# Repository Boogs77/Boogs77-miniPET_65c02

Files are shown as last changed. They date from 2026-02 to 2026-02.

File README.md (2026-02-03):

# miniPET: 65C02-Based Retro Computer

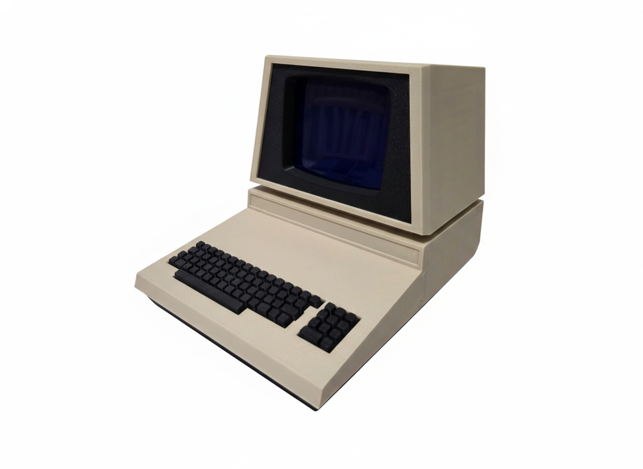
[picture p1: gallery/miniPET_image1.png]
Main Photo


The **Boogs77-miniPET** is a compact, high-performance 8-bit computer inspired by the iconic Commodore PET aesthetics. Built around the **W65C02S** processor, this project utilizes the modular architecture of the [BO6502 System](https://github.com/Boogs77/BO6502_65C02-based_modular_computer) and integrates it into a custom-designed, 3D-printed enclosure.

---

## 🧠 System Architecture & Modules

The internal logic of the miniPET is derived directly from the modular boards of the BO6502 project. Each core component follows the same electrical and logical specifications:

### ⚙️ Core Processing Unit (CPU, RAM, ROM)
The system's "brain" and memory management are based on the high-reliability design of the BO6502:
* **CPU:** Western Design Center **W65C02S**, allowing for modern high-speed operation while maintaining full 6502 compatibility. Reference: [BO6502 CPU](https://github.com/Boogs77/BO6502_65C02-based_modular_computer/tree/main/BO6502%20CPU).
* **Clock:** System operates with a stable **1MHz** clock frequency. Reference: [BO6502 CPU](https://github.com/Boogs77/BO6502_65C02-based_modular_computer/tree/main/BO6502%20CPU).

### 🗺️ Memory Map
The memory layout is organized to ensure compatibility with the system firmware and modular hardware:
* **RAM (32KB):** Mapped from **$0000** to **$7FFF**. Reference: [BO6502 RAM](https://github.com/Boogs77/BO6502_65C02-based_modular_computer/tree/main/BO6502%20RAM).
* **ROM (32KB):** Mapped from **$8000** to **$FFFF**. Reference: [BO6502 ROM](https://github.com/Boogs77/BO6502_65C02-based_modular_computer/tree/main/BO6502%20ROM).

### 📟 Display Interface (BIGLCD)
The visual output is handled by the **BIGLCD** module. 
* **Addressing:** The module is mapped and accessible at memory address **$D19X**.
* **Reference:** [BO6502 BIGLCD](https://github.com/Boogs77/BO6502_65C02-based_modular_computer/tree/main/BO6502%20BIGLCD).

### ⌨️ Keyboard Input
Input is managed via a dedicated matrix keyboard interface.
* **Addressing:** The keyboard is mapped and accessible at memory address **$D18X**.
* **Reference:** [BO6502 KeyBoard Module](https://github.com/Boogs77/BO6502_65C02-based_modular_computer/tree/main/BO6502%20KEYb).

### 🔌 Serial Communication
Asynchronous communication is provided for external terminal access.
* **Addressing:** Accessible at the **$CXXX** memory range.
* **Reference:** [BO6502 Serial Module](https://github.com/Boogs77/BO6502_65C02-based_modular_computer/tree/main/BO6502%20SERIAL).

---

## 💻 Software & Firmware

The Boogs77-miniPET features a classic software environment for 6502 enthusiasts:
* **System Monitor:** The computer implements the legendary **Wozmon** monitor, providing a low-level interface for memory inspection and machine code execution.
* **Microsoft BASIC:** The firmware includes **MS BASIC**, allowing for high-level programming.
* **Execution:** BASIC can be launched directly from the monitor by executing from location **$8000**.

---

## 🏗️ Enclosure & 3D Design

One of the most distinctive features of this project is its custom case, modified using **Autodesk Fusion 360** from the original design at [commodorepetmini.com](https://commodorepetmini.com/). The case was printed on an **Anycubic Kobra S1**.

<p align="center">
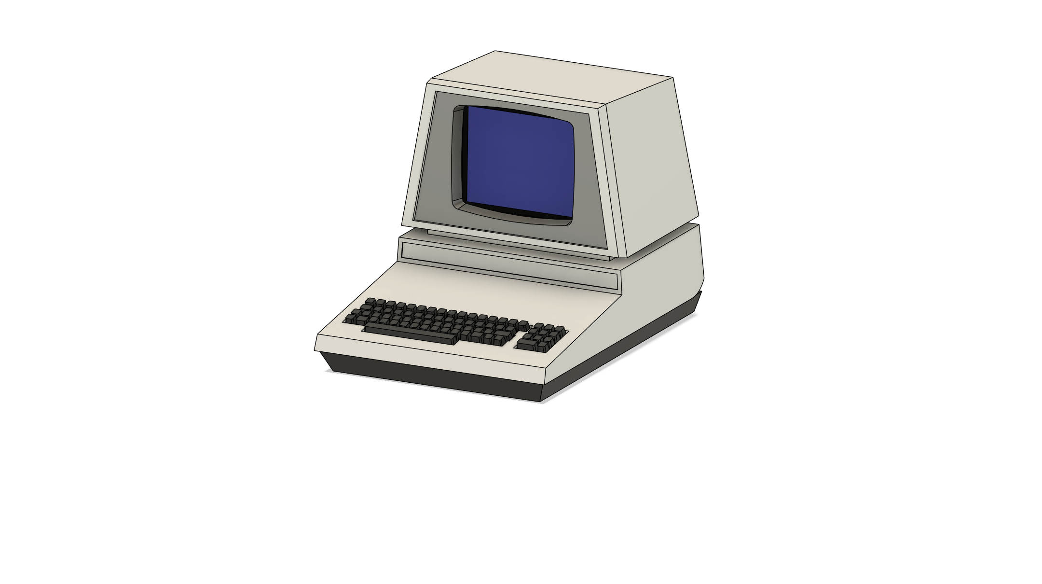
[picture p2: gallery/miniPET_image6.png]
  
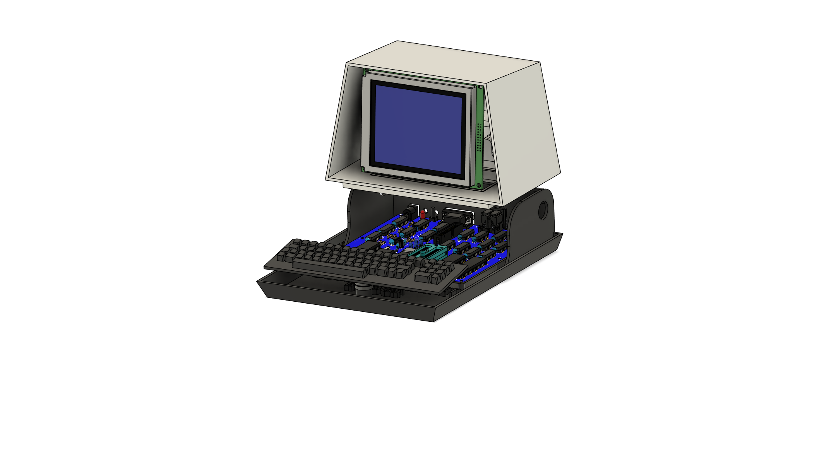
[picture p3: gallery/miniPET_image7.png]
  
</p>

---

## 📋 Bill of Materials (BOM)

| Component | Description | Quantity |
| :--- | :--- | :--- |
| **W65C02S** | CMOS 8-bit Microprocessor | 1 |
| **AS6C62256** | 32K x 8 Static RAM | 1 |
| **AT28C256** | 32K x 8 EEPROM | 1 |
| **W65C22 (VIA)** | Versatile Interface Adapter | 2 |
| **NE555** | Precision Timer (Reset Circuit) | 1 |
| **BIGLCD** | High Contrast LCD Module | 1 |

👉 **[View Full BOM for Components](https://github.com/Boogs77/Boogs77-miniPET_65c02/blob/main/export/miniPET_bom.md)**

---

## 🔗 Useful Links & Resources

To replicate this build, you can refer to the following hardware files:

* **Eagle Design Files:** [Project PCB Schematics & Layouts](https://github.com/Boogs77/Boogs77-miniPET_65c02/tree/main/eagle)
* **CPU Module:** [BO6502 CPU Reference](https://github.com/Boogs77/BO6502_65C02-based_modular_computer/tree/main/BO6502%20CPU)
* **ROM Module:** [BO6502 ROM Reference](https://github.com/Boogs77/BO6502_65C02-based_modular_computer/tree/main/BO6502%20ROM)
* **RAM Module:** [BO6502 RAM Reference](https://github.com/Boogs77/BO6502_65C02-based_modular_computer/tree/main/BO6502%20RAM)
* **Serial Module:** [BO6502 Serial Reference](https://github.com/Boogs77/BO6502_65C02-based_modular_computer/tree/main/BO6502%20SERIAL)
* **Keyboard Module:** [BO6502 KeyBoard Reference](https://github.com/Boogs77/BO6502_65C02-based_modular_computer/tree/main/BO6502%20KEYb)
* **Display Module:** [BO6502 BIGLCD Reference](https://github.com/Boogs77/BO6502_65C02-based_modular_computer/tree/main/BO6502%20BIGLCD)

---

## 🖼️ Project Gallery

Internal assembly and detailed realization stages:

<p align="center">
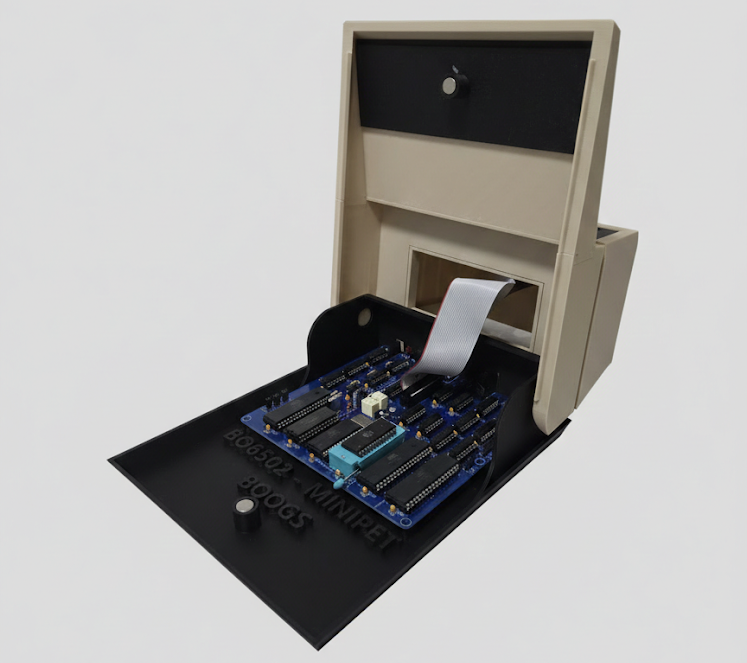
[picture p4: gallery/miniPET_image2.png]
  
  
</p>
<p align="center">
  
  
</p>

---
*Created by Boogs77 - 2026*

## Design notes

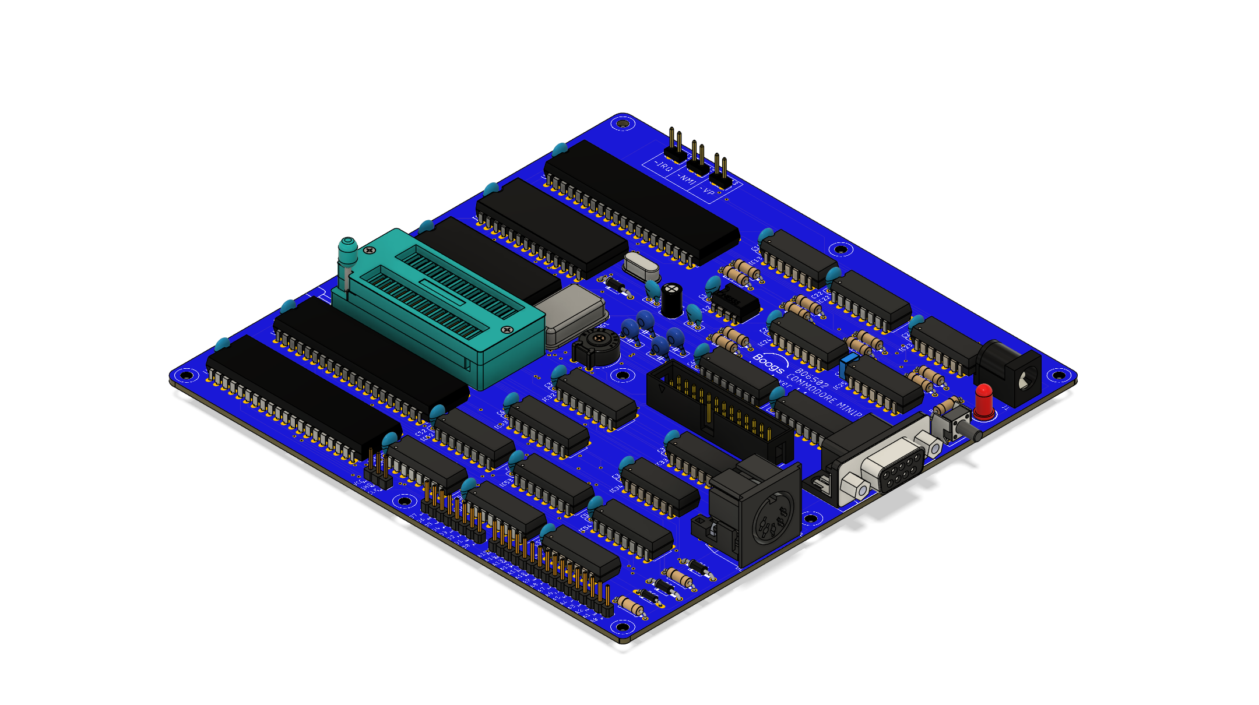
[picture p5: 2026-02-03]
gallery/miniPET_final.png

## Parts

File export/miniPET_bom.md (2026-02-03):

# 📑 Bill of Materials (BOM): miniPET 1.0

**Project:** miniPET
**Export Date:** 02/02/2026
**Source File:** `miniPET_final.sch`

---

### 🧠 Integrated Circuits (IC) & Logic
| Qty | Part | Value | Description | Package |
| :--- | :--- | :--- | :--- | :--- |
| 1 | **U11** | 65C02 | 8-bit CMOS CPU | DIL40 |
| 2 | **U51, U61** | 65C22 | VIA (Versatile Interface Adapter) | DIL40 |
| 1 | **U43** | 65C51 | ACIA (Serial Interface) | DIL28 |
| 1 | **IC21** | HM62256 | Static RAM (SRAM) | DIL28-6 |
| 1 | **ZX1-28C256** | 228-1277-00-0602J | Zero Insertion Force (ZIF) Socket | 228-1277-00-0602J |
| 7 | **IC22, IC32, IC42, IC54, IC55, IC56, IC63** | 74AC138N | 3-to-8 Decoder/Demultiplexer | DIL16 |
| 4 | **IC23, IC24, IC33, IC34** | 74HC08N | Quad 2-input AND gate | DIL14 |
| 2 | **IC52, IC53** | 74HCT595N | 8-bit Shift Register with output latch | DIL16 |
| 1 | **IC41** | MAX232 | RS232 Transceiver | DIL16 |
| 1 | **IC12** | NE555 | General purpose bipolar Timer | DIL-08 |
| 1 | **IC13** | 74HCT04N | Hex INVERTER | DIL14 |
| 1 | **IC57** | 74HCT14N | Hex Schmitt Trigger Inverter | DIL14 |
| 1 | **IC25** | 74HCT00N | Quad 2-input NAND gate | DIL14 |

---

### ⚡ Resistors & Potentiometers
| Qty | Part | Value | Description | Package |
| :--- | :--- | :--- | :--- | :--- |
| 5 | **R14, R15, R16, R17, R18** | 3.3K | Standard Resistor | 0207/10 |
| 2 | **R1, R31** | 330 | Standard Resistor | 0207/10 |
| 2 | **R11, R41** | 1M | Standard Resistor | 0207/10 |
| 1 | **R12** | 47k | Standard Resistor | 0207/10 |
| 1 | **R13** | 1k | Standard Resistor | 0207/10 |
| 1 | **R51** | 15K | Standard Resistor | 0207/10 |
| 1 | **R62** | 220 | Standard Resistor | 0207/10 |
| 1 | **R61** | 10K | Potentiometer | PT-10 |

---

### 🔋 Capacitors
| Qty | Part | Value | Description | Package |
| :--- | :--- | :--- | :--- | :--- |
| 22 | **C11, C13-15, C21-25, C31-34, C46-48, C51-57, C61, C63** | 100n | Ceramic Capacitor (Decoupling) | C025-025X050 |
| 4 | **C41, C42, C43, C44** | 1u | Ceramic Capacitor | C050-025X075 |
| 1 | **C12** | 10uF | Polarized Capacitor | B45181A |
| 1 | **C45** | 20p | Ceramic Capacitor (for Crystal) | C025-025X050 |

---

### 💎 Diodes & Crystals
| Qty | Part | Value | Description | Package |
| :--- | :--- | :--- | :--- | :--- |
| 1 | **Q41** | 1.8432MHz | Crystal | HC49/S |
| 1 | **QG1** | - | Crystal Oscillator | DIL14S |
| 3 | **D41, D51, D61** | BS140 / SB140 | Diode (Equiv. 1N4004) | DO41-10 |
| 1 | **D52** | 1N4148 | Fast Signal Diode | DO35-7 |
| 1 | **LED1** | RED | 5mm LED | LED5MM |

---

### 🔌 Connectors, Switches & Display
| Qty | Part | Value | Description | Package |
| :--- | :--- | :--- | :--- | :--- |
| 1 | **LCD1** | DS-G160128STBWW | Graphic LCD | PAK100 |
| 1 | **J1** | POWER | DC Power Jack | SPC4078 |
| 1 | **X1** | RS232-DB9 | SUB-D 9-pin Connector | F09HP |
| 1 | **X2** | DIN 5 pin | Female DIN Connector | MAB5SH |
| 1 | **SW1** | MOMENTARY | Momentary Pushbutton (Reset) | TACTILE_RA |
| 11 | **JP1, JP11-13, JP2A-B, JP3A-D** | - | Jumper Headers | JP1 / JP2 / JP4 |

---

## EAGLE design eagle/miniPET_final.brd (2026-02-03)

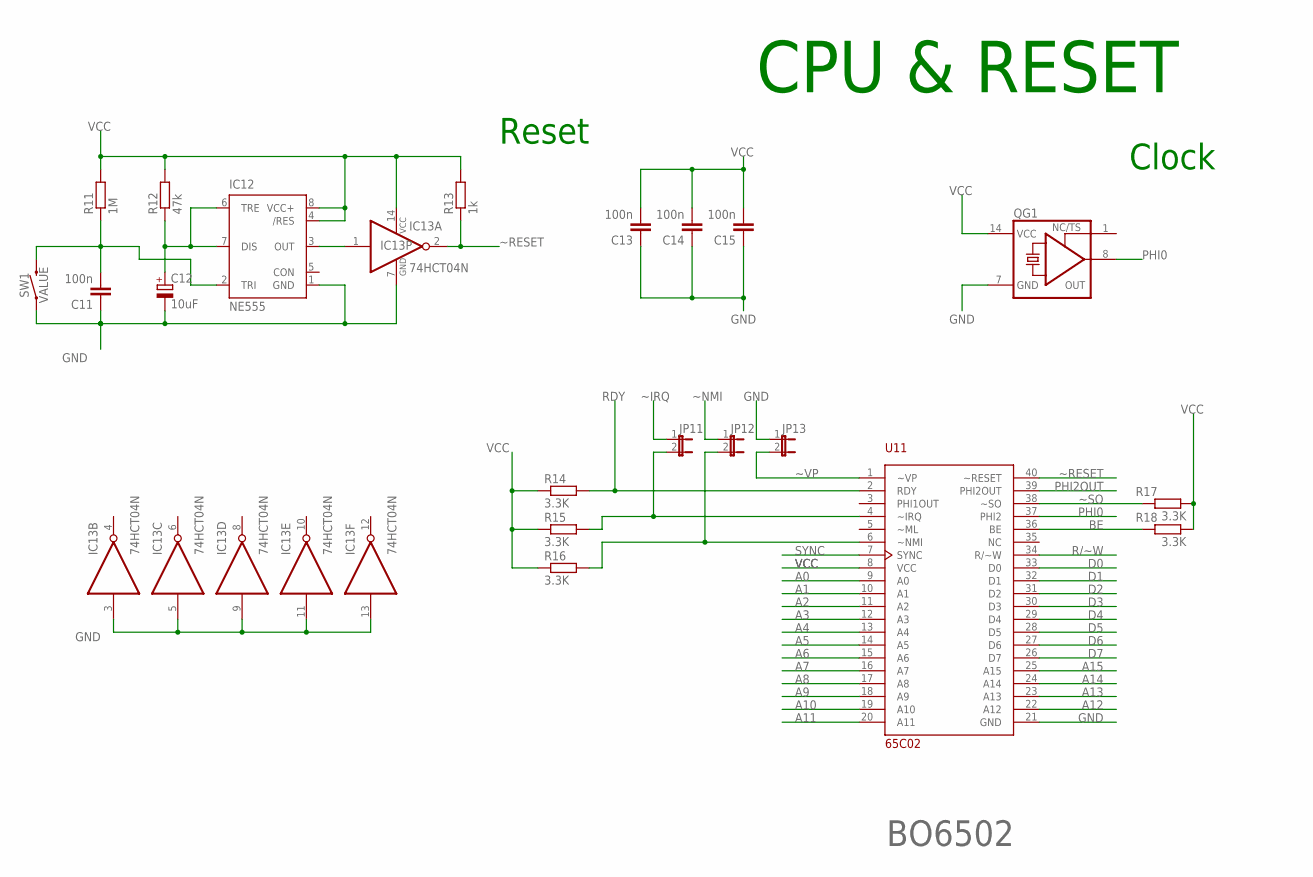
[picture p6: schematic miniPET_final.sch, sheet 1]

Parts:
C11, C13, C14, C15: 100n; C025-025X050
C12: 10uF; B45181A
IC12: NE555; DIL-08
IC13: 74HCT04N; DIL14
JP11, JP12, JP13: JP1E; JP1
QG1: XO-14; DIL14S
R11: 1M; 0207/10
R12: 47k; 0207/10
R13: 1k; 0207/10
R14, R15, R16, R17, R18: 3.3K; 0207/10
SW1: MOMENTARY-SWITCH-SPST-PTH-RIGHT-ANGLE-8-020; TACTILE_SWITCH_PTH_RA_8-020
U11: 65C02; DIL40

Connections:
A0: U11.9 (A0); also elsewhere on the board
A1: U11.10 (A1); also elsewhere on the board
A2: U11.11 (A2); also elsewhere on the board
A3: U11.12 (A3); also elsewhere on the board
A4: U11.13 (A4); also elsewhere on the board
A5: U11.14 (A5); also elsewhere on the board
A6: U11.15 (A6); also elsewhere on the board
A7: U11.16 (A7); also elsewhere on the board
A8: U11.17 (A8); also elsewhere on the board
A9: U11.18 (A9); also elsewhere on the board
A10: U11.19 (A10); also elsewhere on the board
A11: U11.20 (A11); also elsewhere on the board
A12: U11.22 (A12); also elsewhere on the board
A13: U11.23 (A13); also elsewhere on the board
A14: U11.24 (A14); also elsewhere on the board
A15: U11.25 (A15); also elsewhere on the board
BE: R18.1, U11.36 (BE)
D0: U11.33 (D0); also elsewhere on the board
D1: U11.32 (D1); also elsewhere on the board
D2: U11.31 (D2); also elsewhere on the board
D3: U11.30 (D3); also elsewhere on the board
D4: U11.29 (D4); also elsewhere on the board
D5: U11.28 (D5); also elsewhere on the board
D6: U11.27 (D6); also elsewhere on the board
D7: U11.26 (D7); also elsewhere on the board
GND: C11.1, C12.-, C13.1, C14.1, C15.1, IC12.1 (GND), IC13.3 (I), IC13.5 (I), IC13.7 (GND), IC13.9 (I), IC13.11 (I), IC13.13 (I), JP13.1, QG1.7 (GND), SW1.1, U11.21 (GND); also elsewhere on the board
unnamed: JP11.2, R15.2, U11.4 (~IRQ)
unnamed: JP12.2, R16.2, U11.6 (~NMI)
unnamed: C12.+, IC12.6 (TRE), IC12.7 (DIS), R12.1
unnamed: C11.2, IC12.2 (TRI), R11.1, SW1.2
unnamed: IC12.3 (OUT), IC13.1 (I)
PHI0: QG1.8 (OUT), U11.37 (PHI2); also elsewhere on the board
PHI2OUT: U11.39 (PHI2OUT)
R/~W: U11.34 (R/~W); also elsewhere on the board
RDY: R14.2, U11.2 (RDY)
SYNC: U11.7 (SYNC)
VCC: C13.2, C14.2, C15.2, IC12.4 (/RES), IC12.8 (VCC+), IC13.14 (VCC), QG1.14 (VCC), R11.2, R12.2, R13.2, R14.1, R15.1, R16.1, R17.2, R18.2, U11.8 (VCC); also elsewhere on the board
~IRQ: JP11.1; also elsewhere on the board
~NMI: JP12.1
~RESET: IC13.2 (O), R13.1, U11.40 (~RESET); also elsewhere on the board
~SO: R17.1, U11.38 (~SO)
~VP: JP13.2, U11.1 (~VP)

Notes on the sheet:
BO6502
CPU & RESET
Clock
Reset

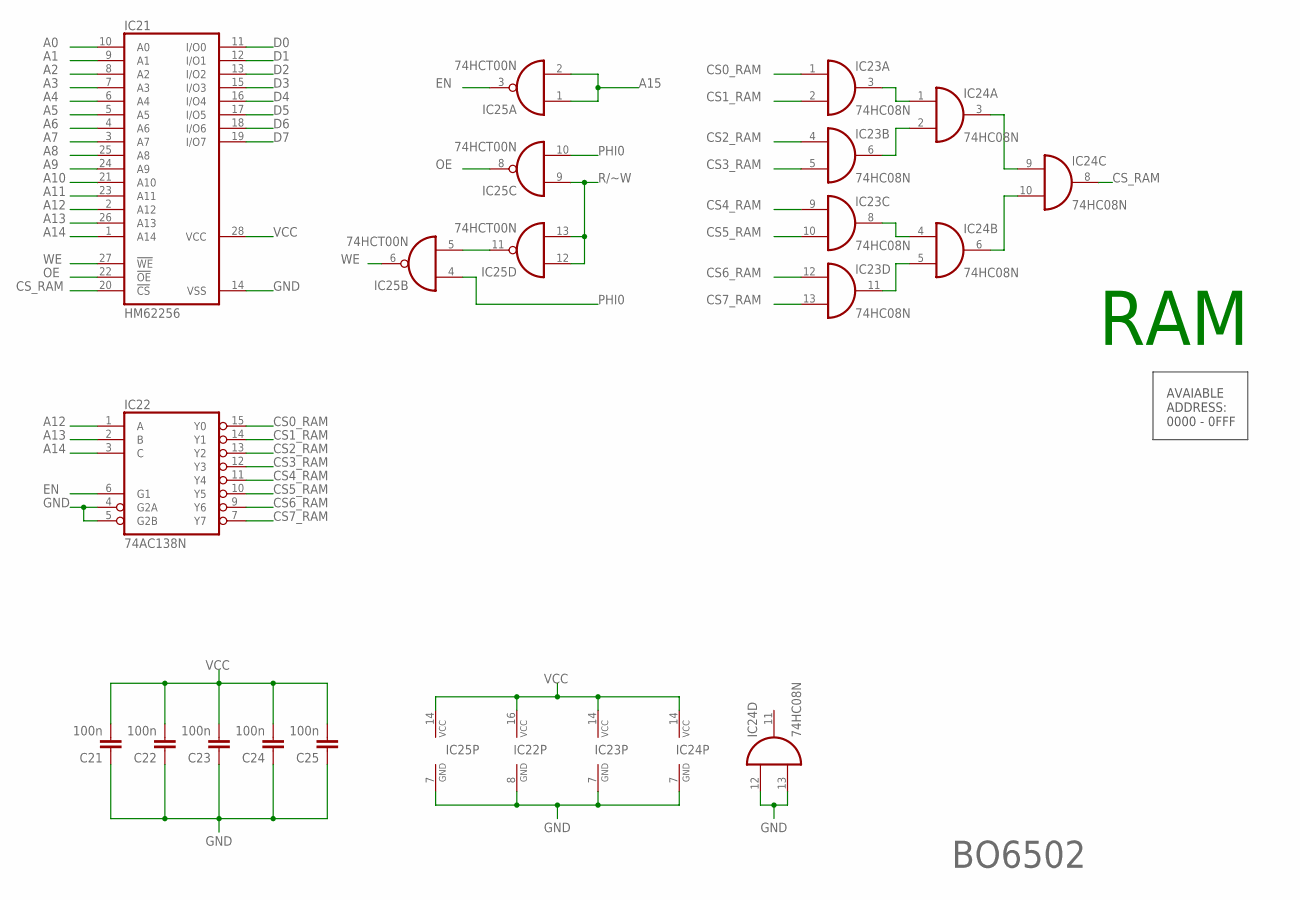
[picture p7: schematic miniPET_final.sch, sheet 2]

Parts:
C21, C22, C23, C24, C25: 100n; C025-025X050
IC21: HM62256; DIL28-6
IC22: 74AC138N; DIL16
IC23, IC24: 74HC08N; DIL14
IC25: 74HCT00N; DIL14

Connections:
A0: IC21.10 (A0); also elsewhere on the board
A1: IC21.9 (A1); also elsewhere on the board
A2: IC21.8 (A2); also elsewhere on the board
A3: IC21.7 (A3); also elsewhere on the board
A4: IC21.6 (A4); also elsewhere on the board
A5: IC21.5 (A5); also elsewhere on the board
A6: IC21.4 (A6); also elsewhere on the board
A7: IC21.3 (A7); also elsewhere on the board
A8: IC21.25 (A8); also elsewhere on the board
A9: IC21.24 (A9); also elsewhere on the board
A10: IC21.21 (A10); also elsewhere on the board
A11: IC21.23 (A11); also elsewhere on the board
A12: IC21.2 (A12), IC22.1 (A); also elsewhere on the board
A13: IC21.26 (A13), IC22.2 (B); also elsewhere on the board
A14: IC21.1 (A14), IC22.3 (C); also elsewhere on the board
A15: IC25.1 (I0), IC25.2 (I1); also elsewhere on the board
CS0_RAM: IC22.15 (Y0), IC23.1 (I0)
CS1_RAM: IC22.14 (Y1), IC23.2 (I1)
CS2_RAM: IC22.13 (Y2), IC23.4 (I0)
CS3_RAM: IC22.12 (Y3), IC23.5 (I1)
CS4_RAM: IC22.11 (Y4), IC23.9 (I0)
CS5_RAM: IC22.10 (Y5), IC23.10 (I1)
CS6_RAM: IC22.9 (Y6), IC23.12 (I0)
CS7_RAM: IC22.7 (Y7), IC23.13 (I1)
CS_RAM: IC21.20 (!CS), IC24.8 (O)
D0: IC21.11 (I/O0); also elsewhere on the board
D1: IC21.12 (I/O1); also elsewhere on the board
D2: IC21.13 (I/O2); also elsewhere on the board
D3: IC21.15 (I/O3); also elsewhere on the board
D4: IC21.16 (I/O4); also elsewhere on the board
D5: IC21.17 (I/O5); also elsewhere on the board
D6: IC21.18 (I/O6); also elsewhere on the board
D7: IC21.19 (I/O7); also elsewhere on the board
EN: IC22.6 (G1), IC25.3 (O)
GND: C21.1, C22.1, C23.1, C24.1, C25.1, IC21.14 (VSS), IC22.4 (G2A), IC22.5 (G2B), IC22.8 (GND), IC23.7 (GND), IC24.7 (GND), IC24.12 (I0), IC24.13 (I1), IC25.7 (GND); also elsewhere on the board
unnamed: IC25.5 (I1), IC25.11 (O)
unnamed: IC23.3 (O), IC24.1 (I0)
unnamed: IC23.6 (O), IC24.2 (I1)
unnamed: IC23.8 (O), IC24.4 (I0)
unnamed: IC23.11 (O), IC24.5 (I1)
unnamed: IC24.3 (O), IC24.9 (I0)
unnamed: IC24.6 (O), IC24.10 (I1)
OE: IC21.22 (!OE), IC25.8 (O)
PHI0: IC25.4 (I0), IC25.10 (I1); also elsewhere on the board
R/~W: IC25.9 (I0), IC25.12 (I0), IC25.13 (I1); also elsewhere on the board
VCC: C21.2, C22.2, C23.2, C24.2, C25.2, IC21.28 (VCC), IC22.16 (VCC), IC23.14 (VCC), IC24.14 (VCC), IC25.14 (VCC); also elsewhere on the board
WE: IC21.27 (!WE), IC25.6 (O)

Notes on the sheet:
RAM
BO6502
AVAIABLE ADDRESS: 0000 - 0FFF

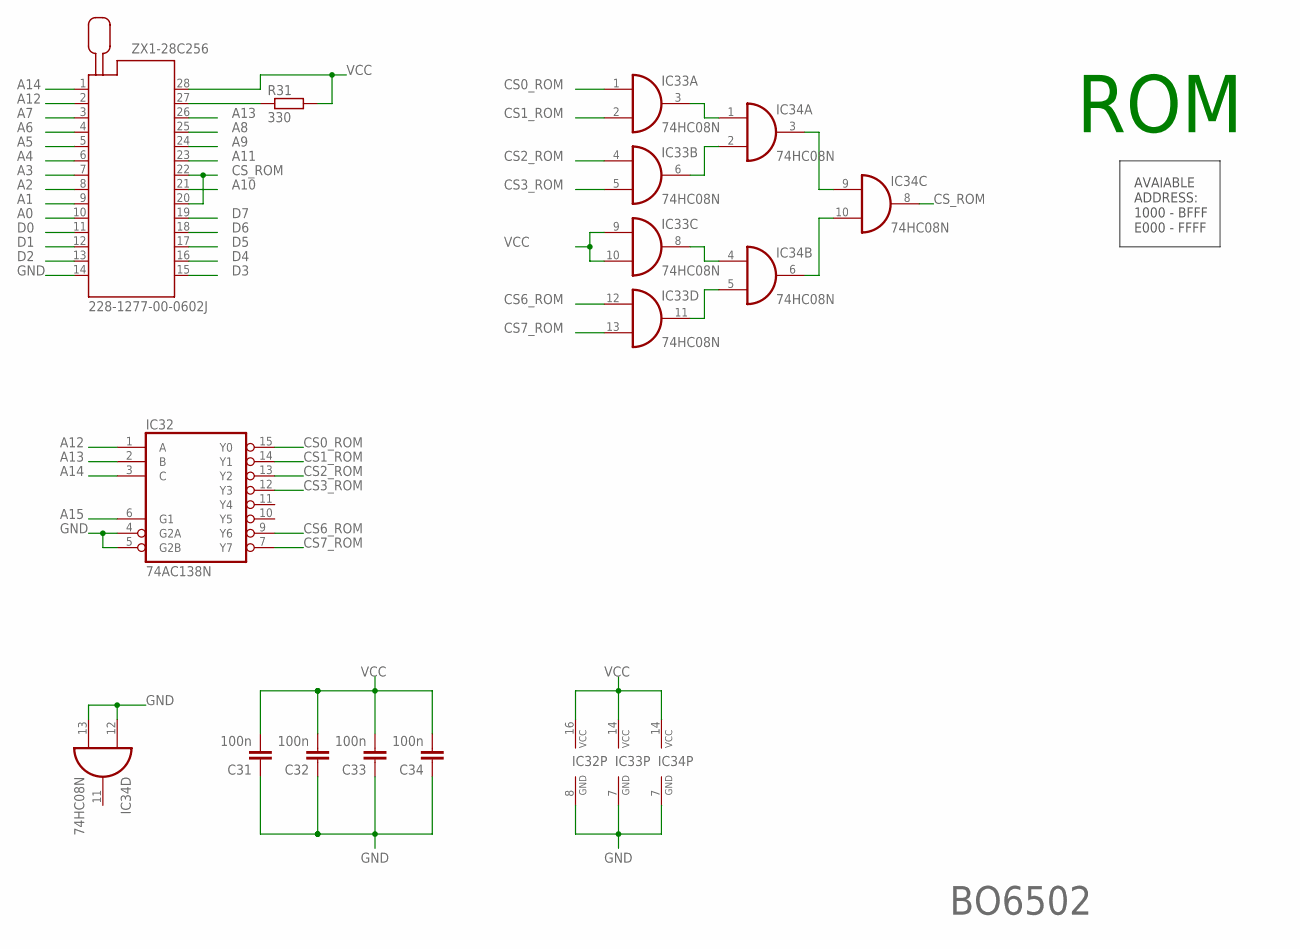
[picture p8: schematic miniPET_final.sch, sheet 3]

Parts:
C31, C32, C33, C34: 100n; C025-025X050
IC32: 74AC138N; DIL16
IC33, IC34: 74HC08N; DIL14
R31: 330; 0207/10
ZX1-28C256: 228-1277-00-0602J

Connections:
A0: ZX1-28C256.10; also elsewhere on the board
A1: ZX1-28C256.9; also elsewhere on the board
A2: ZX1-28C256.8; also elsewhere on the board
A3: ZX1-28C256.7; also elsewhere on the board
A4: ZX1-28C256.6; also elsewhere on the board
A5: ZX1-28C256.5; also elsewhere on the board
A6: ZX1-28C256.4; also elsewhere on the board
A7: ZX1-28C256.3; also elsewhere on the board
A8: ZX1-28C256.25; also elsewhere on the board
A9: ZX1-28C256.24; also elsewhere on the board
A10: ZX1-28C256.21; also elsewhere on the board
A11: ZX1-28C256.23; also elsewhere on the board
A12: IC32.1 (A), ZX1-28C256.2; also elsewhere on the board
A13: IC32.2 (B), ZX1-28C256.26; also elsewhere on the board
A14: IC32.3 (C), ZX1-28C256.1; also elsewhere on the board
A15: IC32.6 (G1); also elsewhere on the board
CS0_ROM: IC32.15 (Y0), IC33.1 (I0)
CS1_ROM: IC32.14 (Y1), IC33.2 (I1)
CS2_ROM: IC32.13 (Y2), IC33.4 (I0)
CS3_ROM: IC32.12 (Y3), IC33.5 (I1)
CS6_ROM: IC32.9 (Y6), IC33.12 (I0)
CS7_ROM: IC32.7 (Y7), IC33.13 (I1)
CS_ROM: IC34.8 (O), ZX1-28C256.20, ZX1-28C256.22
D0: ZX1-28C256.11; also elsewhere on the board
D1: ZX1-28C256.12; also elsewhere on the board
D2: ZX1-28C256.13; also elsewhere on the board
D3: ZX1-28C256.15; also elsewhere on the board
D4: ZX1-28C256.16; also elsewhere on the board
D5: ZX1-28C256.17; also elsewhere on the board
D6: ZX1-28C256.18; also elsewhere on the board
D7: ZX1-28C256.19; also elsewhere on the board
GND: C31.1, C32.1, C33.1, C34.1, IC32.4 (G2A), IC32.5 (G2B), IC32.8 (GND), IC33.7 (GND), IC34.7 (GND), IC34.12 (I0), IC34.13 (I1), ZX1-28C256.14; also elsewhere on the board
unnamed: R31.1, ZX1-28C256.27
unnamed: IC33.3 (O), IC34.1 (I0)
unnamed: IC33.6 (O), IC34.2 (I1)
unnamed: IC33.8 (O), IC34.4 (I0)
unnamed: IC33.11 (O), IC34.5 (I1)
unnamed: IC34.3 (O), IC34.9 (I0)
unnamed: IC34.6 (O), IC34.10 (I1)
VCC: C31.2, C32.2, C33.2, C34.2, IC32.16 (VCC), IC33.9 (I0), IC33.10 (I1), IC33.14 (VCC), IC34.14 (VCC), R31.2, ZX1-28C256.28; also elsewhere on the board

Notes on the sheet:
ROM
BO6502
AVAIABLE ADDRESS: 1000 - BFFF E000 - FFFF

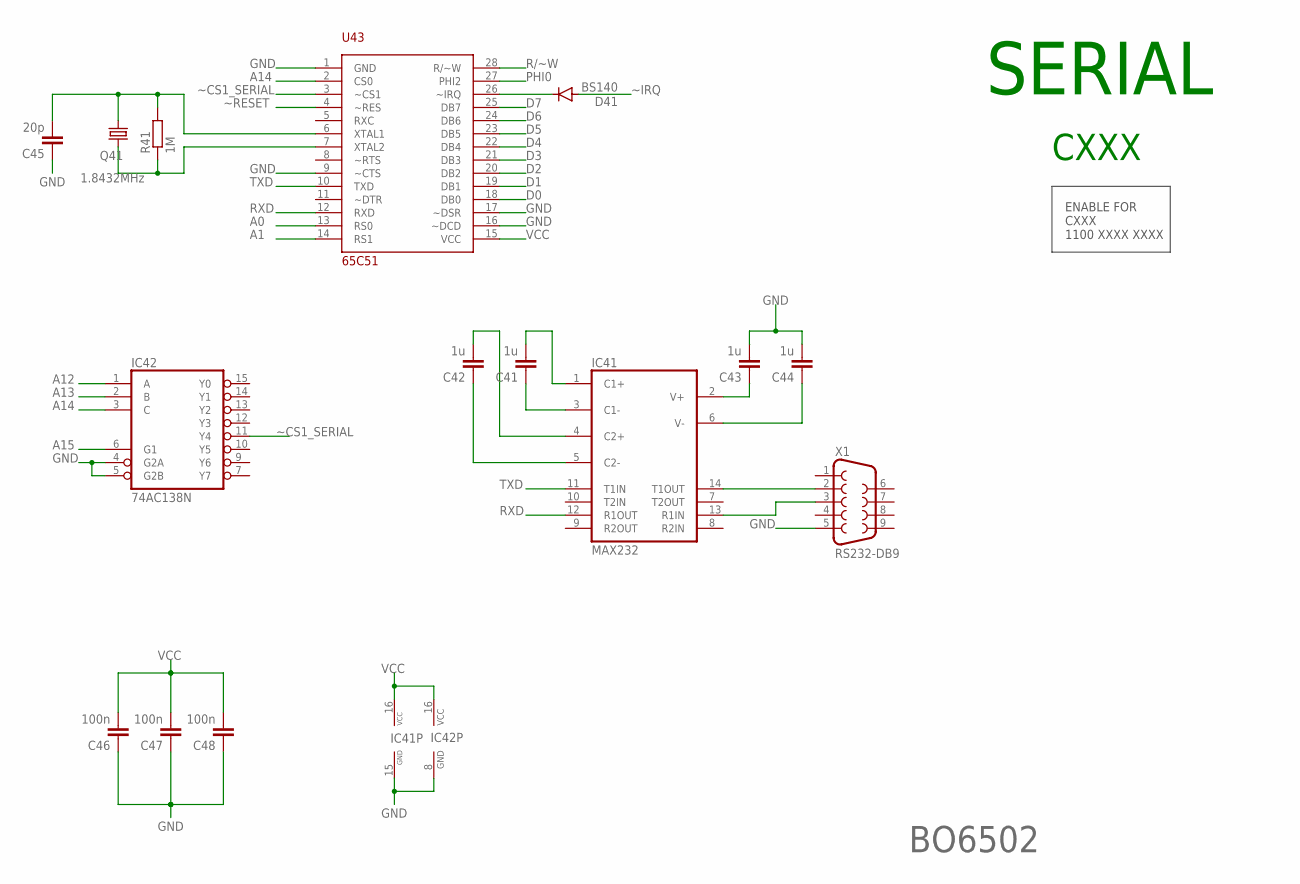
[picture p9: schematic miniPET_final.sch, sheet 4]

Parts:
C41, C42, C43, C44: 1u; C050-025X075
C45: 20p; C025-025X050
C46, C47, C48: 100n; C025-025X050
D41: BS140; DO41-10
IC41: MAX232; DIL16
IC42: 74AC138N; DIL16
Q41: 1.8432MHz; HC49/S
R41: 1M; 0207/10
U43: 65C51; DIL28
X1: RS232-DB9; F09HP

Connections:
A0: U43.13 (RS0); also elsewhere on the board
A1: U43.14 (RS1); also elsewhere on the board
A12: IC42.1 (A); also elsewhere on the board
A13: IC42.2 (B); also elsewhere on the board
A14: IC42.3 (C), U43.2 (CS0); also elsewhere on the board
A15: IC42.6 (G1); also elsewhere on the board
D0: U43.18 (DB0); also elsewhere on the board
D1: U43.19 (DB1); also elsewhere on the board
D2: U43.20 (DB2); also elsewhere on the board
D3: U43.21 (DB3); also elsewhere on the board
D4: U43.22 (DB4); also elsewhere on the board
D5: U43.23 (DB5); also elsewhere on the board
D6: U43.24 (DB6); also elsewhere on the board
D7: U43.25 (DB7); also elsewhere on the board
GND: C43.2, C44.2, C45.1, C46.1, C47.1, C48.1, IC41.15 (GND), IC42.4 (G2A), IC42.5 (G2B), IC42.8 (GND), U43.1 (GND), U43.9 (~CTS), U43.16 (~DCD), U43.17 (~DSR), X1.5; also elsewhere on the board
unnamed: D41.C, U43.26 (~IRQ)
unnamed: C41.2, IC41.1 (C1+)
unnamed: C41.1, IC41.3 (C1-)
unnamed: C42.1, IC41.5 (C2-)
unnamed: IC41.14 (T1OUT), X1.2
unnamed: IC41.13 (R1IN), X1.3
unnamed: C43.1, IC41.2 (V+)
unnamed: C44.1, IC41.6 (V-)
unnamed: C42.2, IC41.4 (C2+)
unnamed: C45.2, Q41.2, R41.2, U43.6 (XTAL1)
unnamed: Q41.1, R41.1, U43.7 (XTAL2)
PHI0: U43.27 (PHI2); also elsewhere on the board
R/~W: U43.28 (R/~W); also elsewhere on the board
RXD: IC41.12 (R1OUT), U43.12 (RXD)
TXD: IC41.11 (T1IN), U43.10 (TXD)
VCC: C46.2, C47.2, C48.2, IC41.16 (VCC), IC42.16 (VCC), U43.15 (VCC); also elsewhere on the board
~CS1_SERIAL: IC42.11 (Y4), U43.3 (~CS1)
~IRQ: D41.A; also elsewhere on the board
~RESET: U43.4 (~RES); also elsewhere on the board

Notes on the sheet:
SERIAL
CXXX
BO6502
ENABLE FOR CXXX 1100 XXXX XXXX

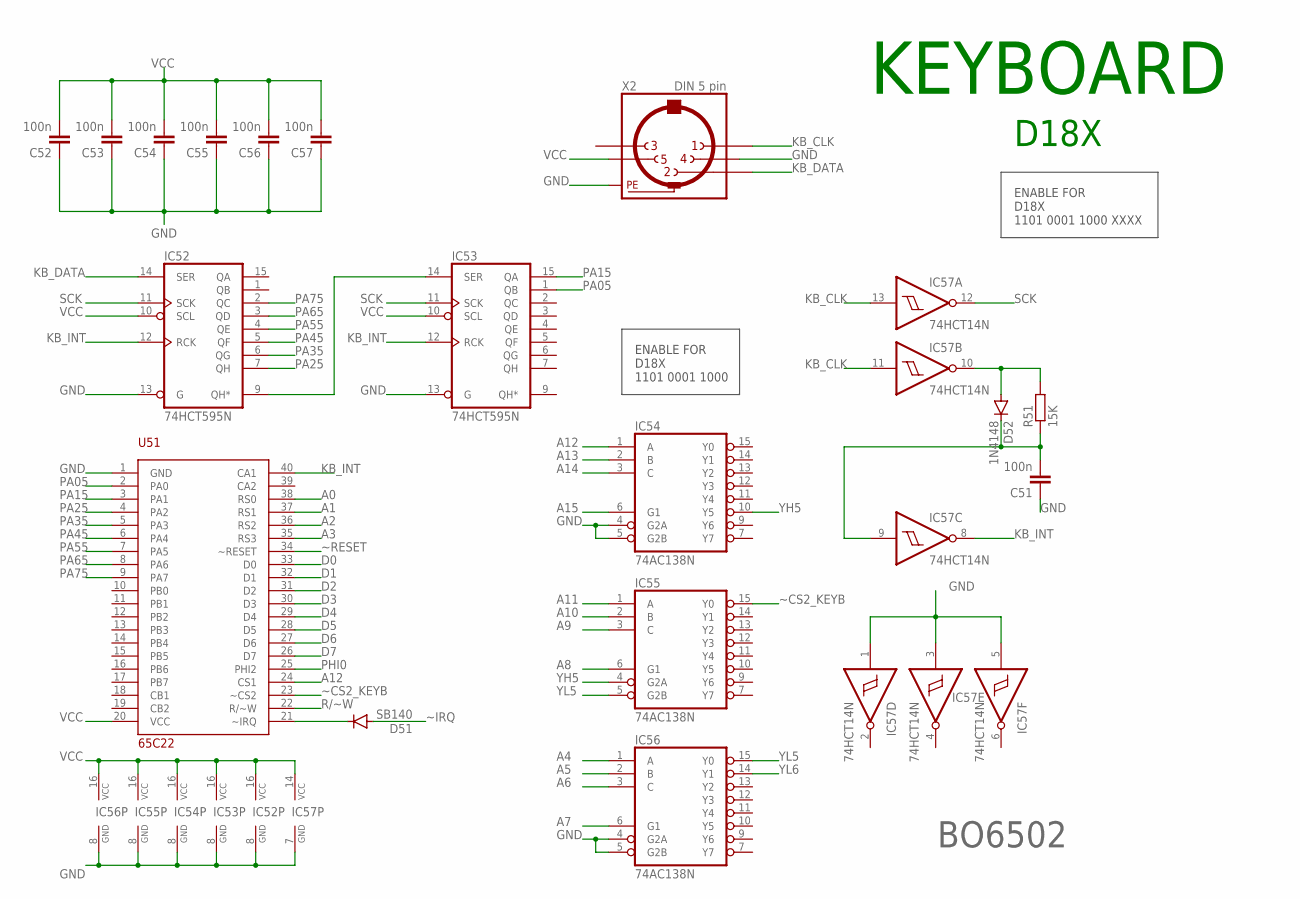
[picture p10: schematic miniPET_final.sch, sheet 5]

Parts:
C51, C52, C53, C54, C55, C56, C57: 100n; C025-025X050
D51: SB140; DO41-10
D52: 1N4148; DO35-7
IC52, IC53: 74HCT595N; DIL16
IC54, IC55, IC56: 74AC138N; DIL16
IC57: 74HCT14N; DIL14
R51: 15K; 0207/10
U51: 65C22; DIL40
X2: DIN 5 pin; MAB5SH

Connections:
A0: U51.38 (RS0); also elsewhere on the board
A1: U51.37 (RS1); also elsewhere on the board
A2: U51.36 (RS2); also elsewhere on the board
A3: U51.35 (RS3); also elsewhere on the board
A4: IC56.1 (A); also elsewhere on the board
A5: IC56.2 (B); also elsewhere on the board
A6: IC56.3 (C); also elsewhere on the board
A7: IC56.6 (G1); also elsewhere on the board
A8: IC55.6 (G1); also elsewhere on the board
A9: IC55.3 (C); also elsewhere on the board
A10: IC55.2 (B); also elsewhere on the board
A11: IC55.1 (A); also elsewhere on the board
A12: IC54.1 (A), U51.24 (CS1); also elsewhere on the board
A13: IC54.2 (B); also elsewhere on the board
A14: IC54.3 (C); also elsewhere on the board
A15: IC54.6 (G1); also elsewhere on the board
D0: U51.33 (D0); also elsewhere on the board
D1: U51.32 (D1); also elsewhere on the board
D2: U51.31 (D2); also elsewhere on the board
D3: U51.30 (D3); also elsewhere on the board
D4: U51.29 (D4); also elsewhere on the board
D5: U51.28 (D5); also elsewhere on the board
D6: U51.27 (D6); also elsewhere on the board
D7: U51.26 (D7); also elsewhere on the board
GND: C51.1, C52.1, C53.1, C54.1, C55.1, C56.1, C57.1, IC52.8 (GND), IC52.13 (G), IC53.8 (GND), IC53.13 (G), IC54.4 (G2A), IC54.5 (G2B), IC54.8 (GND), IC55.8 (GND), IC56.4 (G2A), IC56.5 (G2B), IC56.8 (GND), IC57.1 (I), IC57.3 (I), IC57.5 (I), IC57.7 (GND), U51.1 (GND), X2.4, X2.PE, X2.PE@ (PE); also elsewhere on the board
KB_CLK: IC57.11 (I), IC57.13 (I), X2.1
KB_DATA: IC52.14 (SER), X2.2
KB_INT: IC52.12 (RCK), IC53.12 (RCK), IC57.8 (O), U51.40 (CA1)
unnamed: D51.C, U51.21 (~IRQ)
unnamed: IC52.9 (QH*), IC53.14 (SER)
unnamed: D52.A, IC57.10 (O), R51.2
unnamed: C51.2, D52.C, IC57.9 (I), R51.1
PA05: IC53.1 (QB), U51.2 (PA0)
PA15: IC53.15 (QA), U51.3 (PA1)
PA25: IC52.7 (QH), U51.4 (PA2)
PA35: IC52.6 (QG), U51.5 (PA3)
PA45: IC52.5 (QF), U51.6 (PA4)
PA55: IC52.4 (QE), U51.7 (PA5)
PA65: IC52.3 (QD), U51.8 (PA6)
PA75: IC52.2 (QC), U51.9 (PA7)
PHI0: U51.25 (PHI2); also elsewhere on the board
R/~W: U51.22 (R/~W); also elsewhere on the board
SCK: IC52.11 (SCK), IC53.11 (SCK), IC57.12 (O)
VCC: C52.2, C53.2, C54.2, C55.2, C56.2, C57.2, IC52.10 (SCL), IC52.16 (VCC), IC53.10 (SCL), IC53.16 (VCC), IC54.16 (VCC), IC55.16 (VCC), IC56.16 (VCC), IC57.14 (VCC), U51.20 (VCC), X2.5; also elsewhere on the board
YH5: IC54.10 (Y5), IC55.4 (G2A); also elsewhere on the board
YL5: IC55.5 (G2B), IC56.15 (Y0)
YL6: IC56.14 (Y1); also elsewhere on the board
~CS2_KEYB: IC55.15 (Y0), U51.23 (~CS2)
~IRQ: D51.A; also elsewhere on the board
~RESET: U51.34 (~RESET); also elsewhere on the board

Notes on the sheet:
KEYBOARD
ENABLE FOR D18X 1101 0001 1000
D18X
BO6502
ENABLE FOR D18X 1101 0001 1000 XXXX

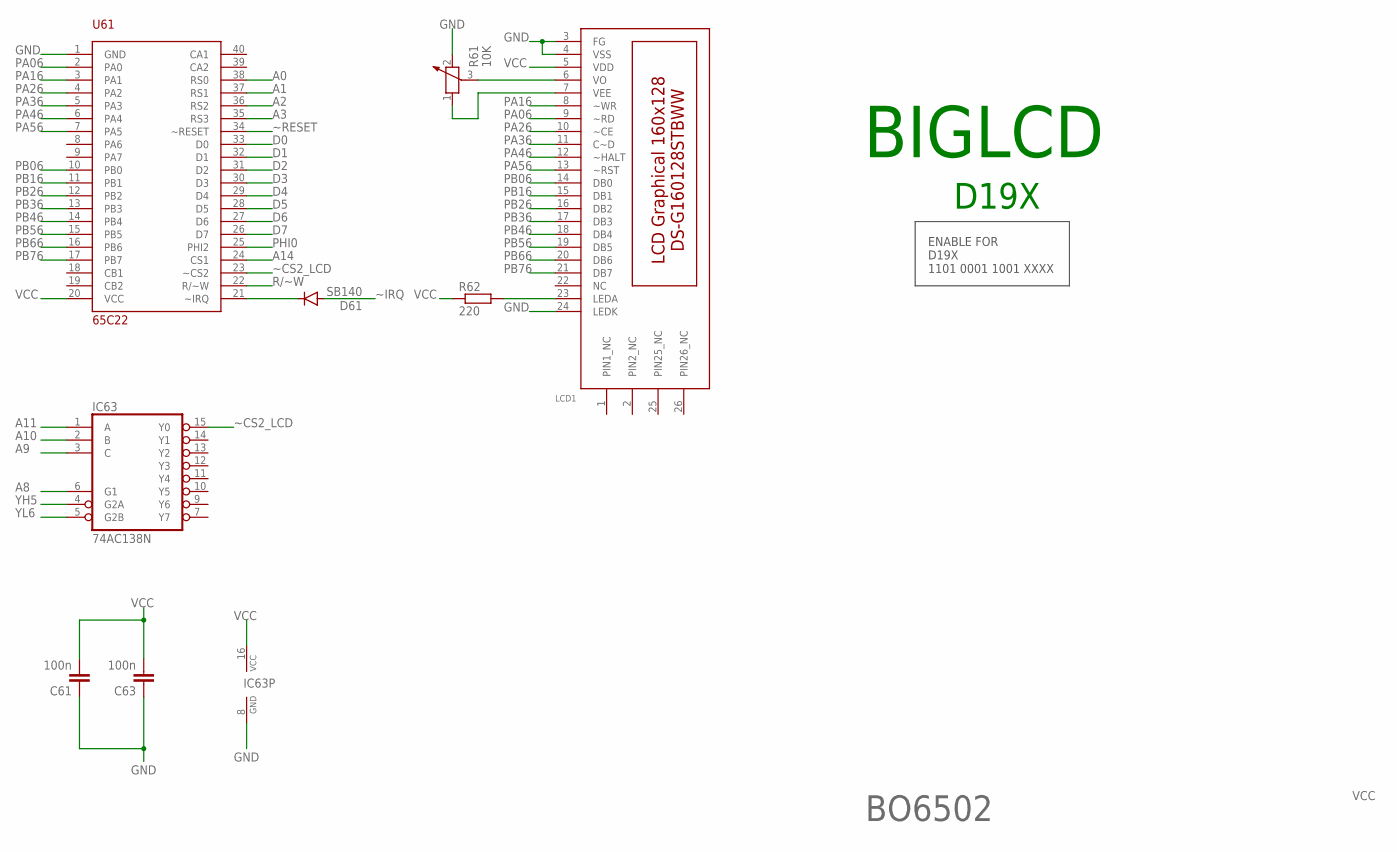
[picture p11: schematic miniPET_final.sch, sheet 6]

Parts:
C61, C63: 100n; C025-025X050
D61: SB140; DO41-10
IC63: 74AC138N; DIL16
LCD1: DS-G160128STBWW; PAK100/2500-26
R61: 10K; PT-10
R62: 220; 0207/10
U61: 65C22; DIL40

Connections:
A0: U61.38 (RS0); also elsewhere on the board
A1: U61.37 (RS1); also elsewhere on the board
A2: U61.36 (RS2); also elsewhere on the board
A3: U61.35 (RS3); also elsewhere on the board
A8: IC63.6 (G1); also elsewhere on the board
A9: IC63.3 (C); also elsewhere on the board
A10: IC63.2 (B); also elsewhere on the board
A11: IC63.1 (A); also elsewhere on the board
A14: U61.24 (CS1); also elsewhere on the board
D0: U61.33 (D0); also elsewhere on the board
D1: U61.32 (D1); also elsewhere on the board
D2: U61.31 (D2); also elsewhere on the board
D3: U61.30 (D3); also elsewhere on the board
D4: U61.29 (D4); also elsewhere on the board
D5: U61.28 (D5); also elsewhere on the board
D6: U61.27 (D6); also elsewhere on the board
D7: U61.26 (D7); also elsewhere on the board
GND: C61.1, C63.1, IC63.8 (GND), LCD1.3 (FG), LCD1.4 (VSS), LCD1.24 (LEDK), R61.2, U61.1 (GND); also elsewhere on the board
unnamed: D61.C, U61.21 (~IRQ)
unnamed: LCD1.6 (VO), R61.3
unnamed: LCD1.7 (VEE), R61.1
unnamed: LCD1.23 (LEDA), R62.2
PA06: LCD1.9 (~RD), U61.2 (PA0)
PA16: LCD1.8 (~WR), U61.3 (PA1)
PA26: LCD1.10 (~CE), U61.4 (PA2)
PA36: LCD1.11 (C~D), U61.5 (PA3)
PA46: LCD1.12 (~HALT), U61.6 (PA4)
PA56: LCD1.13 (~RST), U61.7 (PA5)
PB06: LCD1.14 (DB0), U61.10 (PB0)
PB16: LCD1.15 (DB1), U61.11 (PB1)
PB26: LCD1.16 (DB2), U61.12 (PB2)
PB36: LCD1.17 (DB3), U61.13 (PB3)
PB46: LCD1.18 (DB4), U61.14 (PB4)
PB56: LCD1.19 (DB5), U61.15 (PB5)
PB66: LCD1.20 (DB6), U61.16 (PB6)
PB76: LCD1.21 (DB7), U61.17 (PB7)
PHI0: U61.25 (PHI2); also elsewhere on the board
R/~W: U61.22 (R/~W); also elsewhere on the board
VCC: C61.2, C63.2, IC63.16 (VCC), LCD1.5 (VDD), R62.1, U61.20 (VCC); also elsewhere on the board
YH5: IC63.4 (G2A); also elsewhere on the board
YL6: IC63.5 (G2B); also elsewhere on the board
~CS2_LCD: IC63.15 (Y0), U61.23 (~CS2)
~IRQ: D61.A; also elsewhere on the board
~RESET: U61.34 (~RESET); also elsewhere on the board

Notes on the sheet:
BIGLCD
D19X
BO6502
ENABLE FOR D19X 1101 0001 1001 XXXX

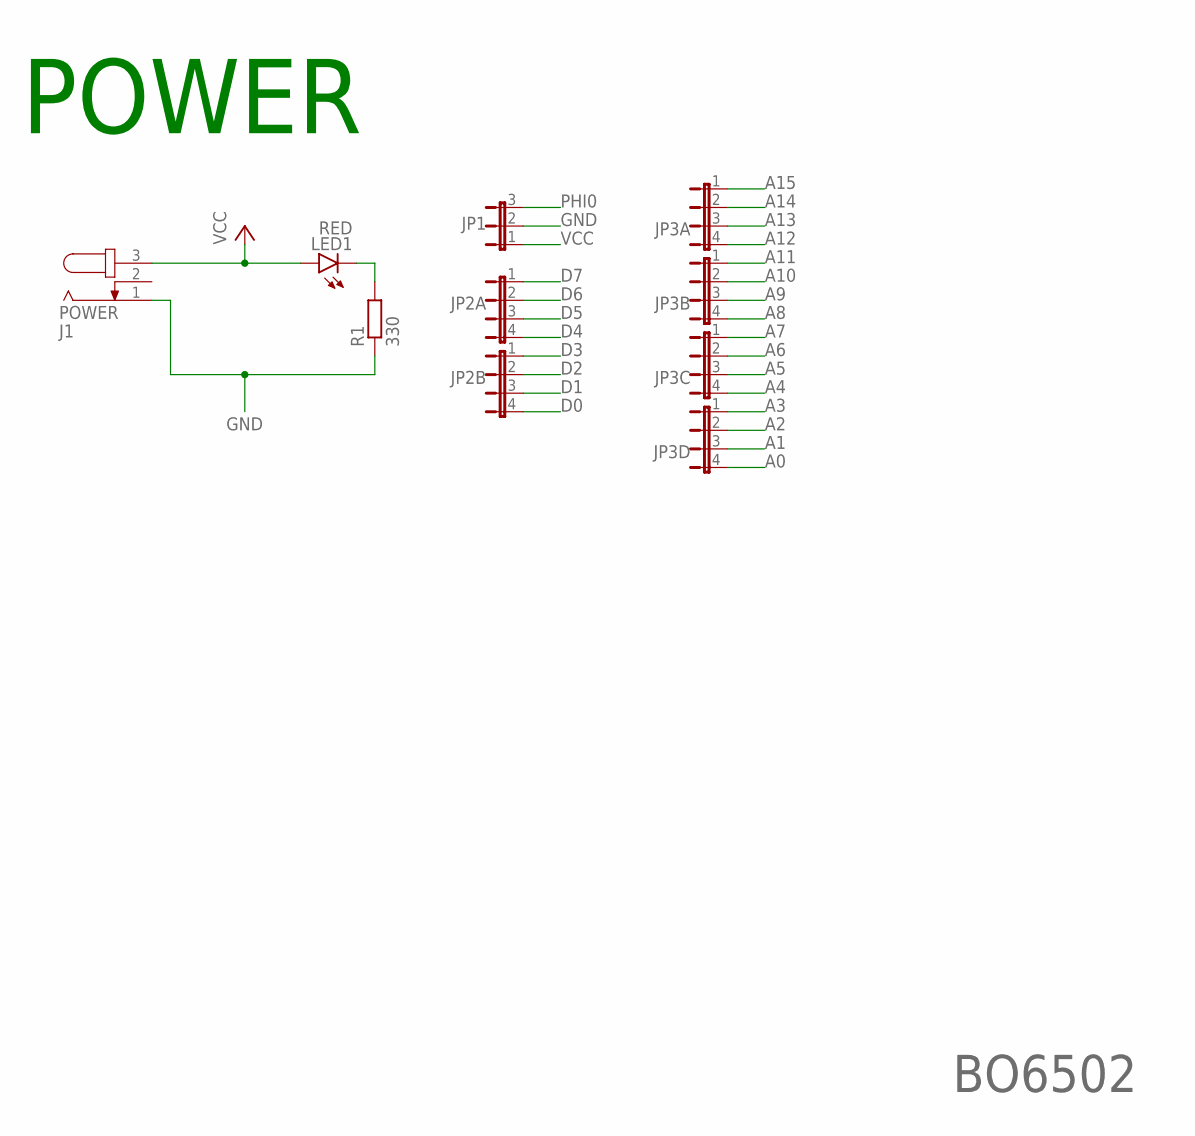
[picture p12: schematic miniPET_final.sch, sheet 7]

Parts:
J1: POWER; SPC4078
JP1: JP2E; JP2
JP2A, JP2B, JP3A, JP3B, JP3C, JP3D: JP4E; JP4
LED1: RED; LED5MM
R1: 330; 0207/10

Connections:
A0: JP3D.4; also elsewhere on the board
A1: JP3D.3; also elsewhere on the board
A2: JP3D.2; also elsewhere on the board
A3: JP3D.1; also elsewhere on the board
A4: JP3C.4; also elsewhere on the board
A5: JP3C.3; also elsewhere on the board
A6: JP3C.2; also elsewhere on the board
A7: JP3C.1; also elsewhere on the board
A8: JP3B.4; also elsewhere on the board
A9: JP3B.3; also elsewhere on the board
A10: JP3B.2; also elsewhere on the board
A11: JP3B.1; also elsewhere on the board
A12: JP3A.4; also elsewhere on the board
A13: JP3A.3; also elsewhere on the board
A14: JP3A.2; also elsewhere on the board
A15: JP3A.1; also elsewhere on the board
D0: JP2B.4; also elsewhere on the board
D1: JP2B.3; also elsewhere on the board
D2: JP2B.2; also elsewhere on the board
D3: JP2B.1; also elsewhere on the board
D4: JP2A.4; also elsewhere on the board
D5: JP2A.3; also elsewhere on the board
D6: JP2A.2; also elsewhere on the board
D7: JP2A.1; also elsewhere on the board
GND: J1.1, JP1.2, R1.1; also elsewhere on the board
unnamed: LED1.K (C), R1.2
PHI0: JP1.3; also elsewhere on the board
VCC: J1.3, JP1.1, LED1.A; also elsewhere on the board

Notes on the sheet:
POWER
BO6502

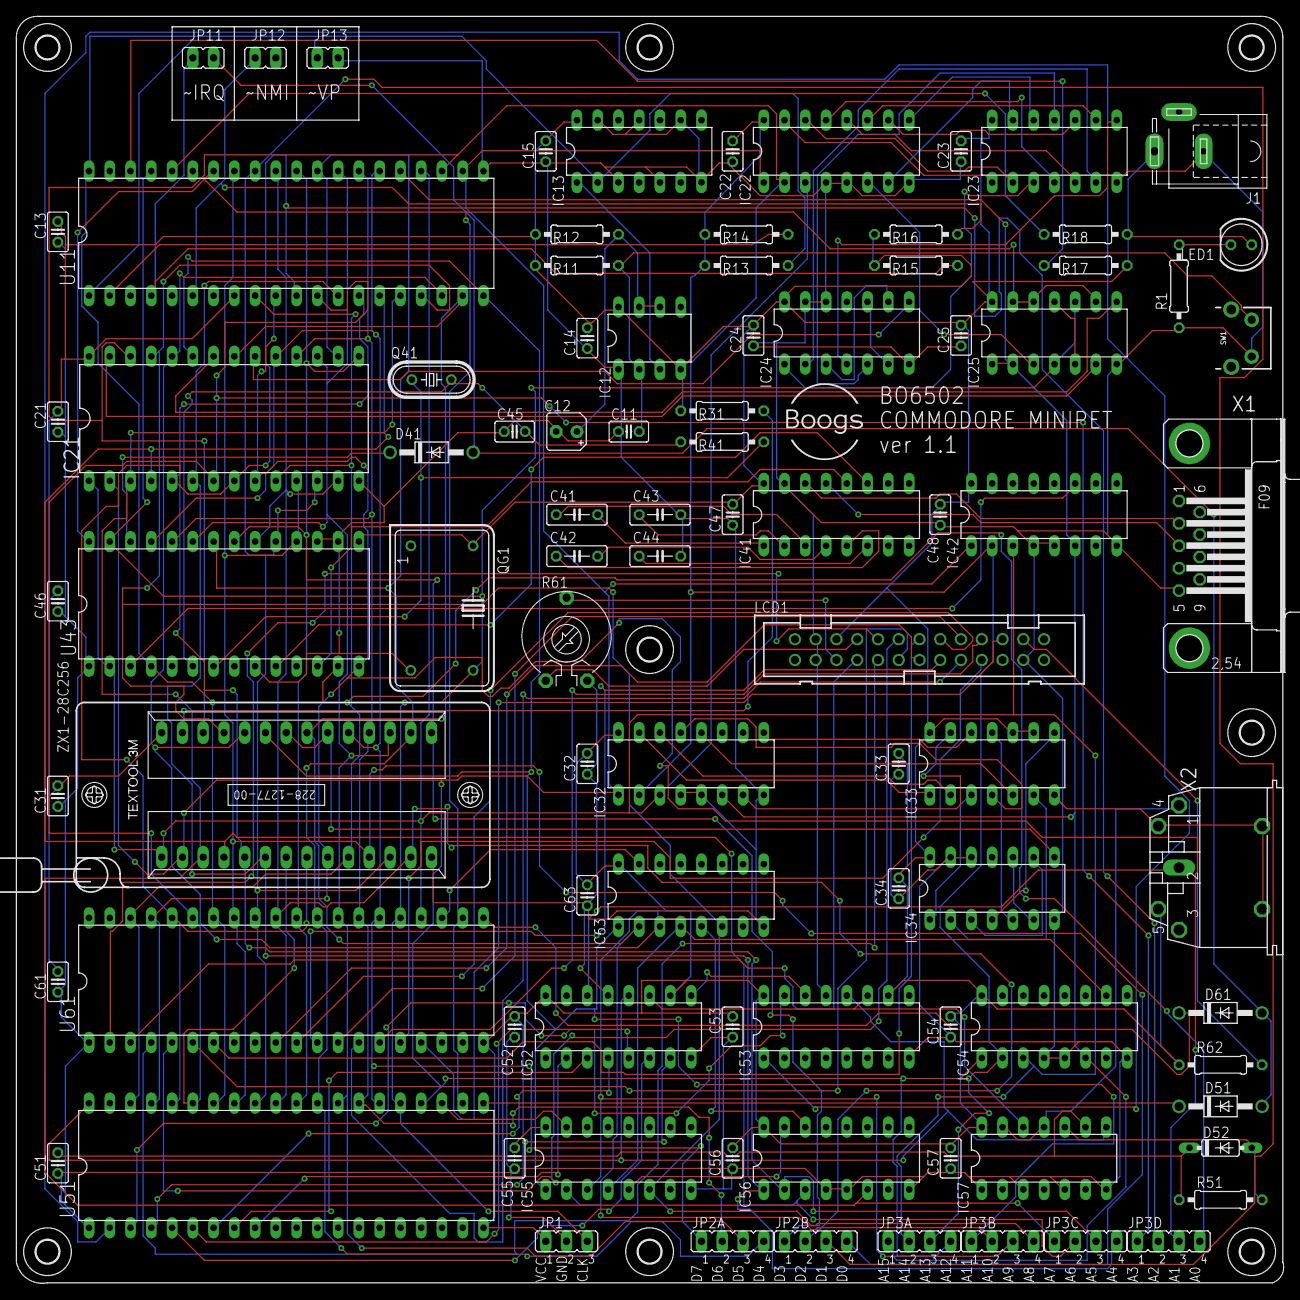
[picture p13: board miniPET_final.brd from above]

Board: 2 copper layers, 155.0 x 155.0 mm, 99 parts (0 on the bottom side), 126 nets.

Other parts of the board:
U$1, U$2, U$3, U$4, U$5, U$6, U$7, U$8: 2,8

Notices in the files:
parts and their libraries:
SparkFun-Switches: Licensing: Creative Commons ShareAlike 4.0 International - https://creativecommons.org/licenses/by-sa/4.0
